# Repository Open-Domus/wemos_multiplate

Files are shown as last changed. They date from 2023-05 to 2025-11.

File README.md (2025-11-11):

# Wemos Multiplate

Wemos Multiplate is a modular, ESPHome-powered front plate for Wemos D1 mini and Wemos S2 mini development boards. It combines presence sensing, environmental telemetry, status lighting, and user inputs into a single wall-friendly enclosure.

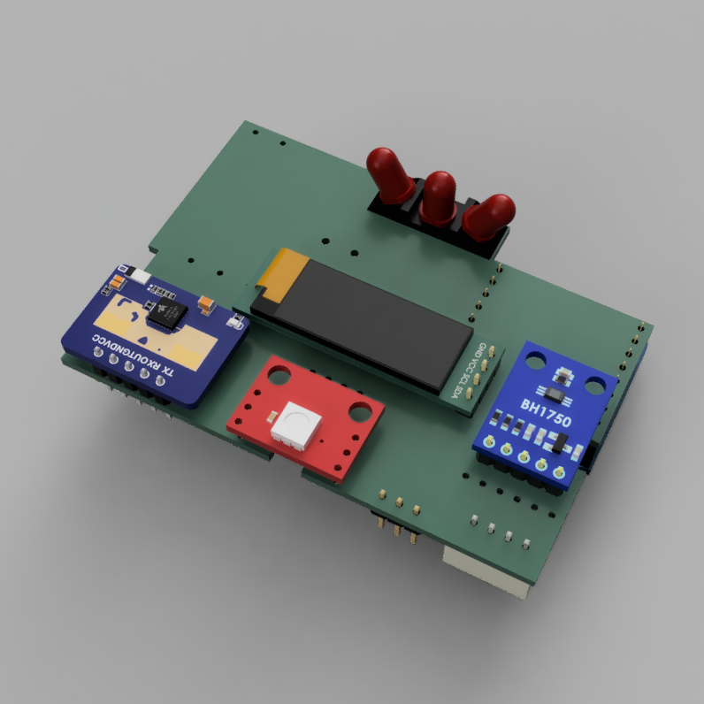
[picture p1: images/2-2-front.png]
front


## Highlights
- Works with Wemos D1 mini (ESP8266) and Wemos S2 mini (ESP32-S2); the S2 mini is strongly recommended if you want every module.
- Integrated 128x64 SSD1306 OLED display with customizable pages.
- Hi-Link LD2410C 24 GHz mmWave presence sensor with optional Bluetooth tuning.
- SHT31-D temperature and humidity probe plus optional BH1750 ambient light and APDS9960 gesture/proximity sensors.
- Two WS2812 addressable LEDs, a piezo buzzer, IR transmitter/receiver, and a header for an external relay module.
- ESPHome package-based configuration lets you enable only the hardware you soldered.

## Repository Layout
- `esphome/` – modular ESPHome configuration split by board (`modules_d1mini/`, `modules_s2mini/`) and shared components (`modules_common/`). Sample automations are under `esphome/automations/`.
- `kicad/wemos-esphome-shield/` – KiCad project, gerbers, STEP models, and release archives for the PCB.

## Hardware Overview
**Base components**
- Wemos D1 mini or Wemos S2 mini dev board (USB-C S2 mini preferred).
- 128x64 I2C OLED display (SSD1306).
- Hi-Link LD2410C mmWave presence sensor.
- Sensirion SHT31-D temperature and humidity sensor.
- Two WS2812 (5 V) addressable LEDs.
- Piezo buzzer with drive transistor.
- TSOP-style IR receiver and 940 nm IR LED pair.

**Optional add-ons**
- BH1750 illuminance sensor.
- APDS9960 gesture/proximity sensor.
- Three front buttons (requires the S2 mini pinout).
- Header for an external 5 V relay module or other accessories.

PCB fabrication files for the latest revision live in `kicad/wemos-esphome-shield/releases/`.

## Getting Started with ESPHome

1. **Install ESPHome**  
   Follow the [ESPHome installation guide](https://esphome.io/guides/installing_esphome.html) (CLI or Home Assistant add-on). CLI examples below assume `pipx install esphome`.

2. **Create secrets**  
   Copy the sample secrets file and edit it with your Wi-Fi and fallback hotspot credentials:
   ```bash
   cp esphome/modules_s2mini/secrets_sample.yaml esphome/secrets.yaml
   ```
   The same `secrets.yaml` is used by both board profiles.

3. **Pick a base profile**  
   - `esphome/multiplate_s2mini.yml` — ESP32-S2 build with every module enabled.  
   - `esphome/multiplate_d1mini.yml` — ESP8266 build with a reduced feature set. Comment out any modules you did not solder to stay within memory limits.

4. **Enable or disable modules**  
   Each module is loaded via the `packages:` section. Comment out a line to disable the corresponding hardware. For example, to skip the gesture sensor:
   ```yaml
   # gesture_sensor: !include modules_common/gesture_sensor.yml
   ```

5. **Build and flash**  
   Connect the board over USB and run:
   ```bash
   esphome run esphome/multiplate_s2mini.yml --device /dev/ttyUSB0
   ```
   After the first successful flash you can go OTA:
   ```bash
   esphome run esphome/your-device-name.yml
   ```

6. **Adopt in Home Assistant**  
   The node exposes all sensors, lights, switches, and buttons via the ESPHome API. Home Assistant will prompt to adopt the new device and automatically create entities.

## Module Reference

| Module | File | Notes |
|---|---|---|
| Core board setup & Wi-Fi | `modules_d1mini/common.yml`, `modules_s2mini/common.yml` | Handles board selection, Wi-Fi credentials, API, OTA. |
| OLED display, pages, and fonts | `modules_common/display.yml`, `font/retrogaming.ttf` | Provides readout and trend pages with a 4 h temperature graph. |
| LD2410C mmWave presence | `modules_d1mini/motion_sensor.yml`, `modules_s2mini/motion_sensor.yml` | Exposes presence, moving/still targets, distance, and Bluetooth control. |
| Temperature & humidity (SHT31-D) | `modules_common/temp_sensor.yml` | Includes a median filter and linear calibration datapoints. |
| Ambient light (BH1750) | `modules_common/light_sensor.yml` | Optional, comment out if the sensor is not populated. |
| Gesture & proximity (APDS9960) | `modules_common/gesture_sensor.yml` | Optional, provides four gesture binary sensors and calibrated proximity. |
| RGB status LEDs | `modules_d1mini/rgb_leds.yml`, `modules_s2mini/rgb_leds.yml` | Two WS2812 LEDs mapped in the sample automations. |
| Buzzer | `modules_d1mini/buzzer.yml`, `modules_s2mini/buzzer.yml` | Template buttons trigger predefined alert patterns. |
| IR transmitter/receiver | `modules_d1mini/ir_remote.yml`, `modules_s2mini/ir_remote.yml` | Exposes `ir_remote` transmitter ID and raw receiver for learning codes. |
| Relay header | `modules_d1mini/relay.yml`, `modules_s2mini/relay.yml` | Optional GPIO-controlled 5 V relay output. |
| Front buttons (S2 mini only) | `modules_s2mini/buttons.yml` | Three debounced GPIO inputs. |
| Automations (display & LEDs) | `automations/display_motion.yml`, `automations/motion_status_leds.yml` | Opt-in template switches to toggle display blanking and LED indicators. |

## Built-in Automations
- `display_motion` keeps the OLED blank until motion is detected, then shows the readout page.
- `motion_status_leds` maps moving and still target detection to the two WS2812 LEDs.

Enable or disable these from the `packages:` block just like the hardware modules.

## Tuning the LD2410C mmWave Sensor
1. Enable the Bluetooth switch entity (`*-ld2410-bluetooth`) exposed by ESPHome.
2. Use the official Android configuration app: <https://play.google.com/store/apps/details?id=com.hlk.hlkradartool>.
3. Connect to the sensor, enter Engineering Mode, and adjust the eight detection gates to match your room layout. Lower values increase sensitivity.
4. Apollo Automation maintains a detailed tuning guide: <https://wiki.apolloautomation.com/books/msr-1/page/how-to-tune-mmwave-using-home-assistant>.

Keeping the heavy tuning UI out of ESPHome reduces load on the D1 mini and shortens boot times.

## Using the IR Remote
Add climate, media, or switch components to your ESPHome profile and reference the shared `ir_remote` transmitter and `ir_rx` receiver IDs. Example:

```yaml
climate:
  - platform: daikin
    name: ${device_name}-climate
    transmitter_id: ir_remote
    receiver_id: ir_rx
```

Use the `remote_receiver` in learning mode (`dump: raw`) to capture codes from your existing remote.

## Manufacturing Files
- Latest gerber sets: `kicad/wemos-esphome-shield/gerber/`
- STEP models for enclosure work: `kicad/wemos-esphome-shield/step/`
- Release bundles (gerbers, BOM, pick-and-place): `kicad/wemos-esphome-shield/releases/`

Send the gerber ZIP to your PCB manufacturer of choice, then populate the board according to the silkscreen and BOM in the release archive.

---

Questions, improvements, or pull requests are welcome!

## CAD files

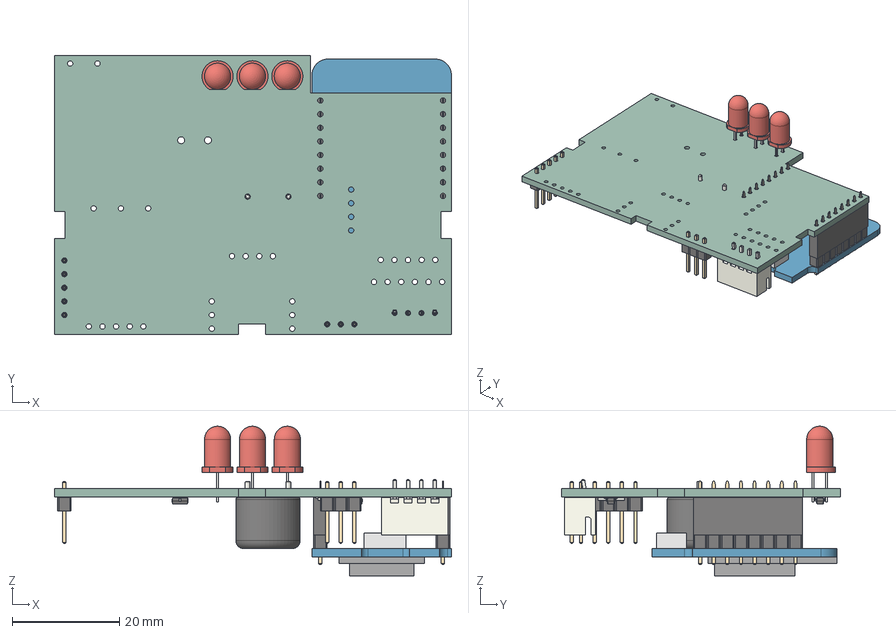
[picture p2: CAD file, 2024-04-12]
kicad/wemos-esphome-shield/step/pcb v2-1.step
74.0 x 52.0 x 27.9 mm
LED_D5.0mm x 3
SOT_23 x 3
R_1206_3216Metric x 8
PinHeader_1x03_P254mm_Vertical
Buzzer_12x95RM76
wemos_d1_mini_light
PinHeader_1x08_P254mm_Vertical x 2
PinSocket_1x08_P254mm_Vertical x 2
JST_B4B_XH_A
PinHeader_1x05_P254mm_Vertical
wemos-esphome-shield PCB

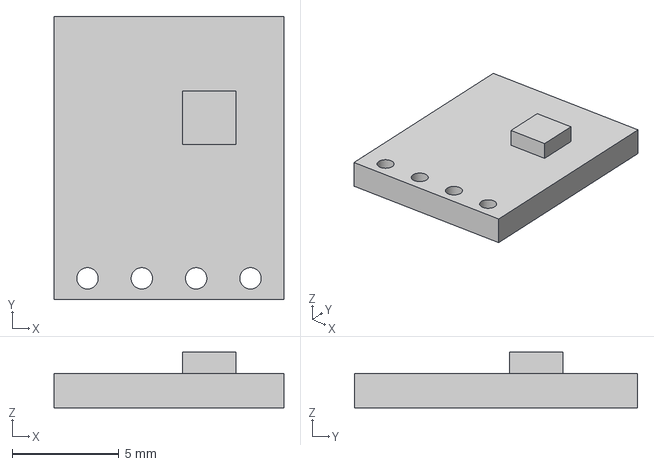
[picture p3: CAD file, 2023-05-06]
kicad/wemos-esphome-shield/step/SHT3X v1.step
10.8 x 13.2 x 2.60 mm

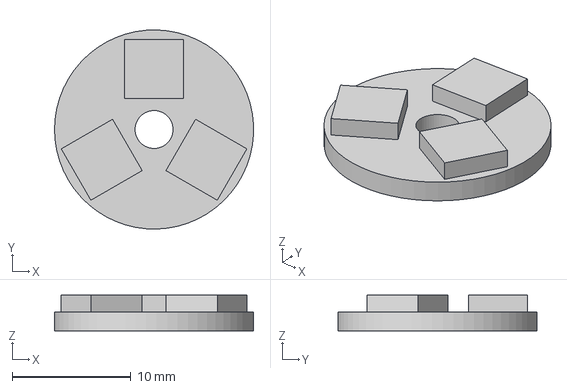
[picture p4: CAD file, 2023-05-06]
kicad/wemos-esphome-shield/step/LED ring v1.step
16.8 x 16.8 x 3.00 mm

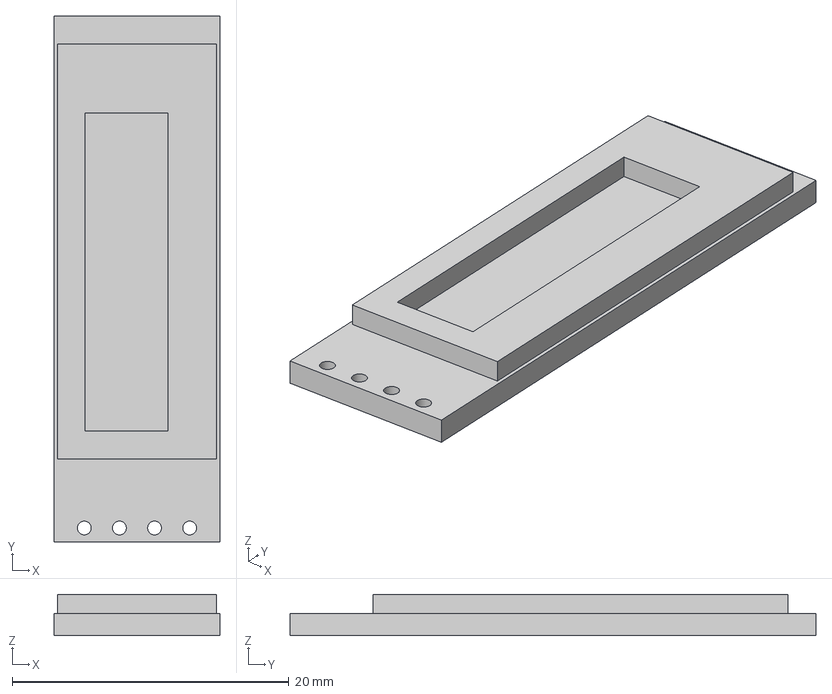
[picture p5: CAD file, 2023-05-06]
kicad/wemos-esphome-shield/step/OLED 0.91 v3.step
12.0 x 38.0 x 3.00 mm

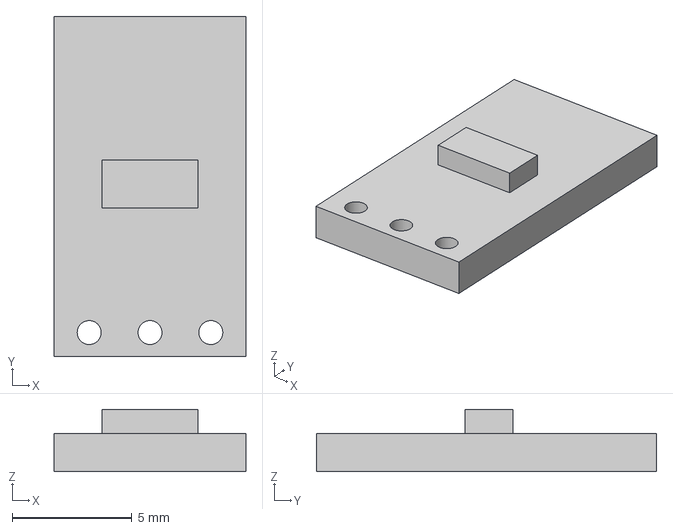
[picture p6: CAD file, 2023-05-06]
kicad/wemos-esphome-shield/step/TEMT6000 v2.step
8.00 x 14.2 x 2.60 mm

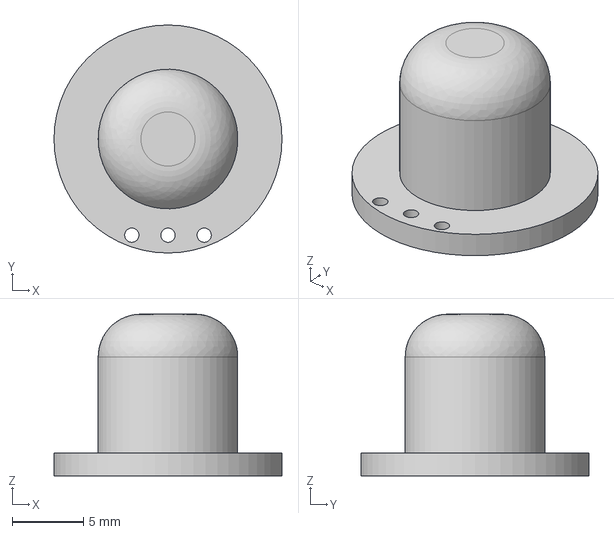
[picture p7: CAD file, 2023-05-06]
kicad/wemos-esphome-shield/step/SR602 v1.step
16.0 x 16.0 x 11.3 mm

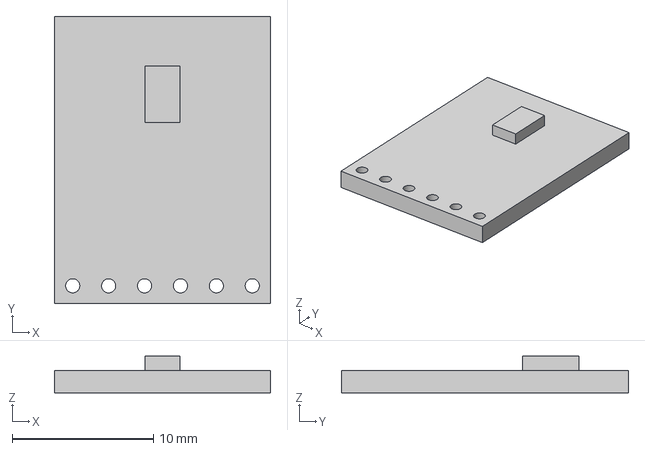
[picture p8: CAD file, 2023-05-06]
kicad/wemos-esphome-shield/step/APDS9960 (new) v3.step
15.3 x 20.3 x 2.60 mm

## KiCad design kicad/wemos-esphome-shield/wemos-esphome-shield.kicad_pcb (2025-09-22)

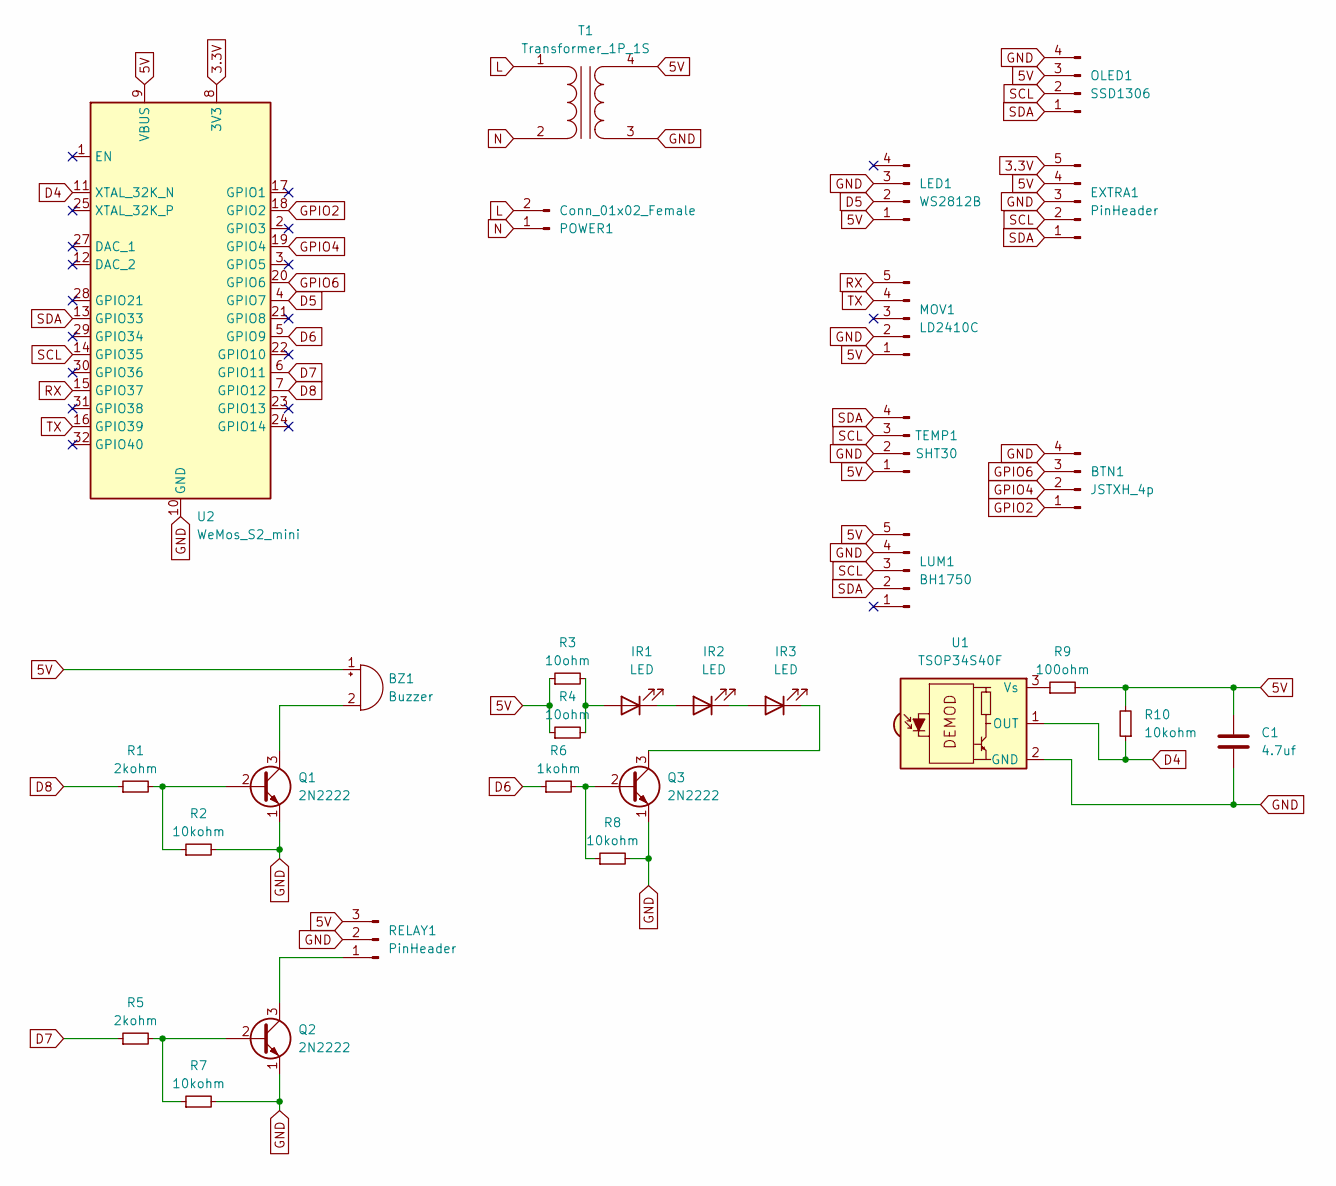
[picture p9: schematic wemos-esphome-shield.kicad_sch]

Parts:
BTN1: JSTXH_4p; JST_XH_B4B-XH-A_1x04_P2.50mm_Vertical
BZ1: Buzzer; Buzzer_12x9.5RM7.6
C1: 4.7uf; C_1206_3216Metric_Pad1.33x1.80mm_HandSolder
EXTRA1: PinHeader; PinHeader_1x05_P2.54mm_Vertical
IR1, IR2, IR3: LED; LED_D5.0mm
LED1: WS2812B; LED breakout
LUM1: BH1750
MOV1: LD2410C
OLED1: SSD1306; SSD1306 OLED 128x64
POWER1: Conn_01x02_Female; TerminalBlock_MetzConnect_Type094_RT03502HBLU_1x02_P5.00mm_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
Q1, Q2, Q3: 2N2222; SOT-23_Handsoldering
R1, R5: 2kohm; R_1206_3216Metric_Pad1.30x1.75mm_HandSolder
R2, R7, R8, R10: 10kohm; R_1206_3216Metric_Pad1.30x1.75mm_HandSolder
R3, R4: 10ohm; R_1206_3216Metric_Pad1.30x1.75mm_HandSolder
R6: 1kohm; R_1206_3216Metric_Pad1.30x1.75mm_HandSolder
R9: 100ohm; R_1206_3216Metric_Pad1.30x1.75mm_HandSolder
RELAY1: PinHeader; PinHeader_1x03_P2.54mm_Vertical
T1: Transformer_1P_1S; 220v AC to 5v DC Transformer
TEMP1: SHT30; JST_XH_B4B-XH-A_1x04_P2.50mm_Vertical
U1: TSOP34S40F; Vishay_MOLD-3Pin
U2: WeMos_S2_mini; WEMOS_S2_mini

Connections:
3.3V: EXTRA1.5, U2.8 (3V3)
5V: BZ1.1 (+), C1.1, EXTRA1.4, LED1.1, LUM1.5, MOV1.1, OLED1.3, R3.1, R4.1, R9.2, R10.2, RELAY1.3, T1.4 (SB), TEMP1.1, U2.9 (VBUS)
D4: R10.1, U1.1 (OUT), U2.11 (XTAL_32K_N)
D5: LED1.2, U2.4 (GPIO7)
D6: R6.1, U2.5 (GPIO9)
D7: R5.1, U2.6 (GPIO11)
D8: R1.1, U2.7 (GPIO12)
GND: BTN1.4, C1.2, EXTRA1.3, LED1.3, LUM1.4, MOV1.2, OLED1.4, Q1.1 (E), Q2.1 (E), Q3.1 (E), R2.2, R7.2, R8.2, RELAY1.2, T1.3 (SA), TEMP1.2, U1.2 (GND), U2.10 (GND), U2.26 (GND)
GPIO2: BTN1.1, U2.18 (GPIO2)
GPIO4: BTN1.2, U2.19 (GPIO4)
GPIO6: BTN1.3, U2.20 (GPIO6)
L: POWER1.2, T1.1 (AA)
N: POWER1.1, T1.2 (AB)
unnamed: BZ1.2 (-), Q1.3 (C)
unnamed: IR1.2 (A), R3.2, R4.2
unnamed: IR1.1 (K), IR2.2 (A)
unnamed: IR2.1 (K), IR3.2 (A)
unnamed: IR3.1 (K), Q3.3 (C)
unnamed: Q1.2 (B), R1.2, R2.1
unnamed: Q2.2 (B), R5.2, R7.1
unnamed: Q2.3 (C), RELAY1.1
unnamed: Q3.2 (B), R6.2, R8.1
unnamed: R9.1, U1.3 (Vs)
RX: MOV1.5, U2.15 (GPIO37)
SCL: EXTRA1.2, LUM1.3, OLED1.2, TEMP1.3, U2.14 (GPIO35)
SDA: EXTRA1.1, LUM1.2, OLED1.1, TEMP1.4, U2.13 (GPIO33)
TX: MOV1.4, U2.16 (GPIO39)

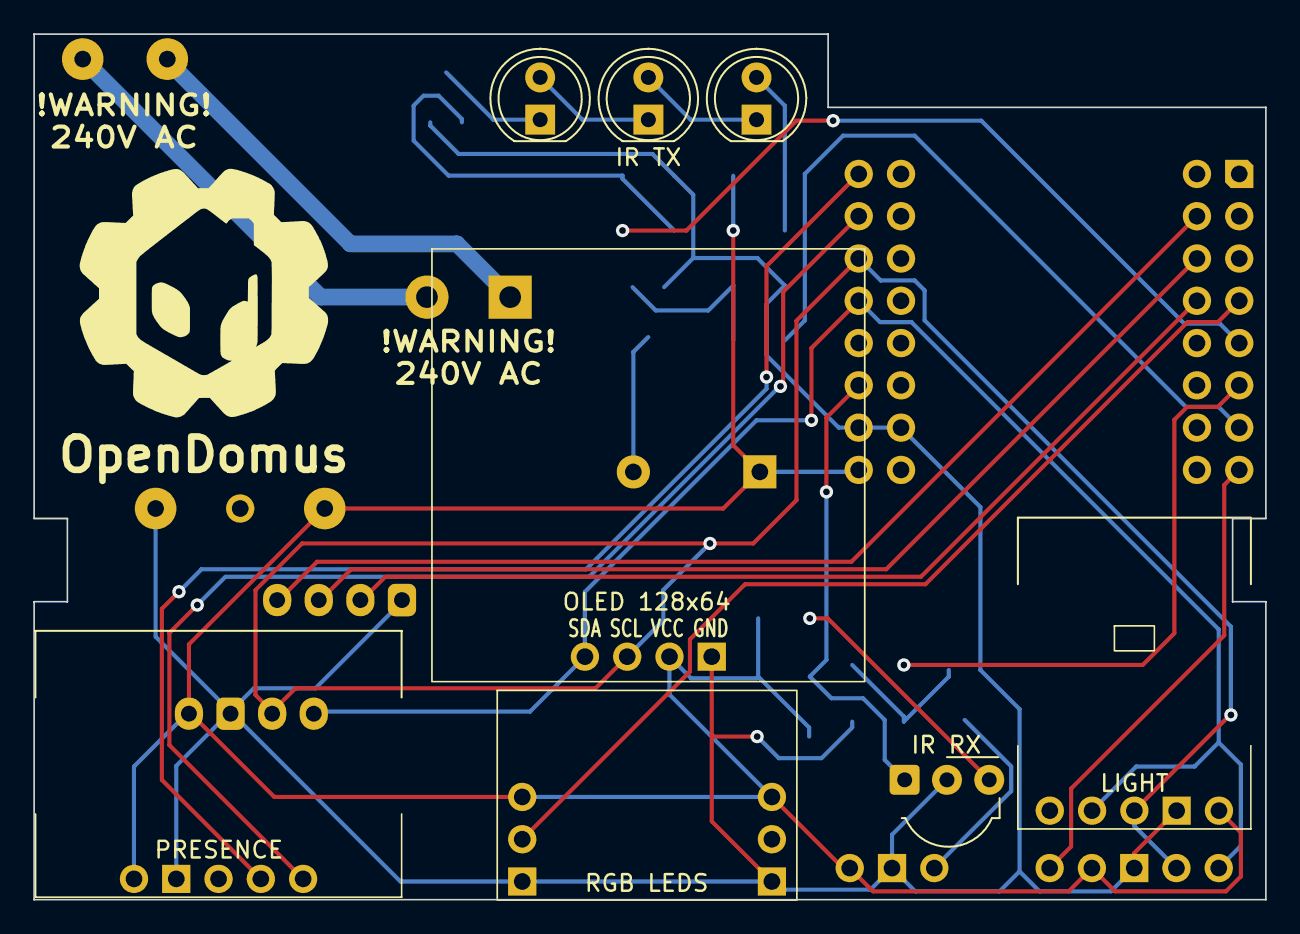
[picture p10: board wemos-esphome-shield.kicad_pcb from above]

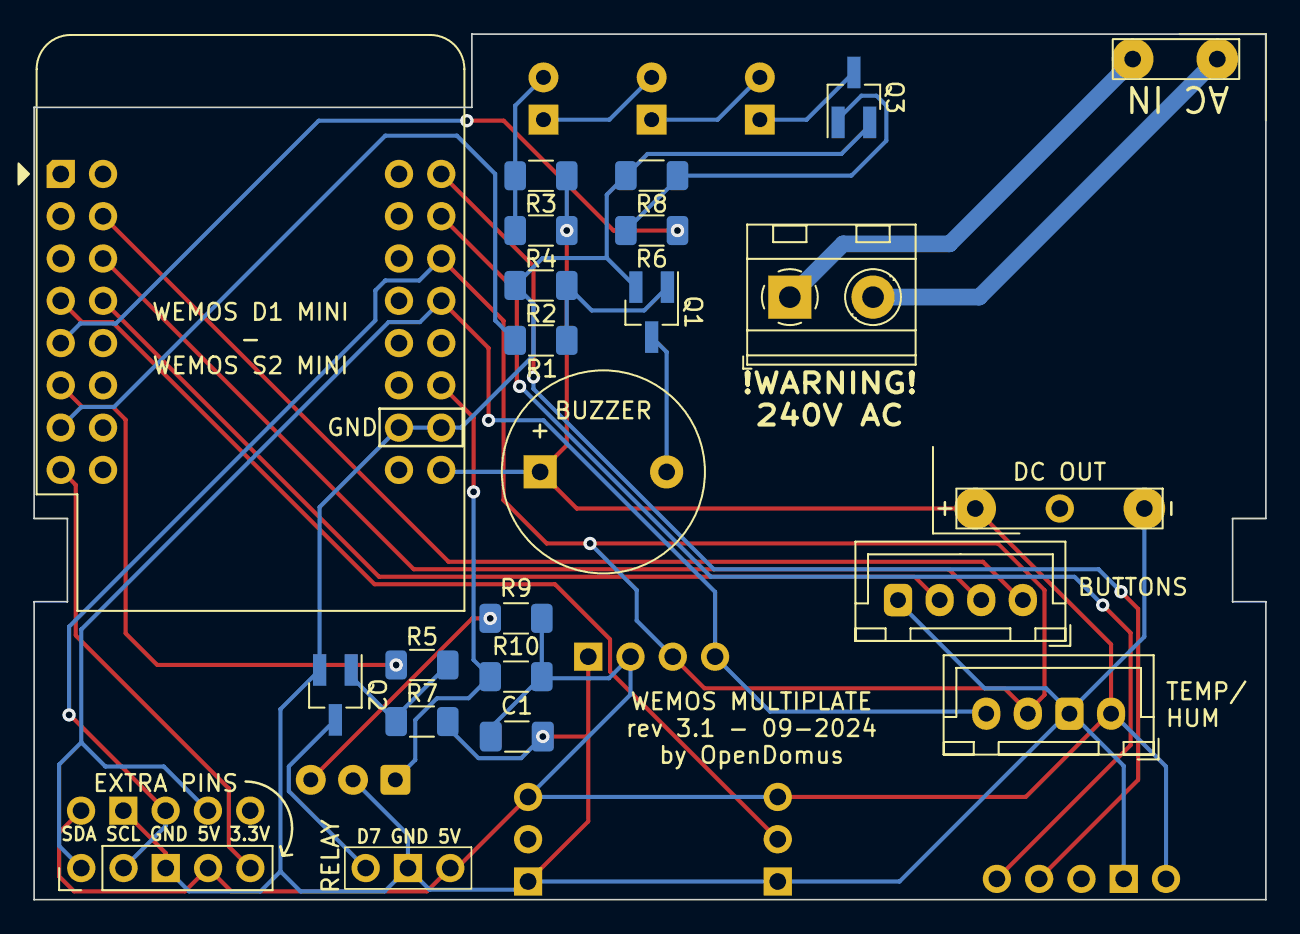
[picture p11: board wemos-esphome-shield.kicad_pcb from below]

Board: 2 copper layers, 74.0 x 52.0 mm, 30 parts (22 on the bottom side), 27 nets.

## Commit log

2023-03-30 move sensors and relay2
    [wemos-esphome-shield.kicad_pcb]
2023-03-30 fix leds footprint
    [wemos-esphome-shield.kicad_pcb]
2023-04-06 Fix some electrical net, new cut edge, new netclasses
    [wemos-esphome-shield.kicad_pcb, wemos-esphome-shield.kicad_sch]
2023-04-06 first routing version
    [wemos-esphome-shield.kicad_pcb]
2023-04-07 update APDS footprint for future compatibility
    [wemos-esphome-shield.kicad_pcb, wemos-esphome-shield.kicad_sch]
2023-04-14 transistor driven relay pin, expose more extra pins, and routing
    [wemos-esphome-shield.kicad_pcb, wemos-esphome-shield.kicad_sch]
2023-04-17 add oled screen pads
    [wemos-esphome-shield.kicad_pcb, wemos-esphome-shield.kicad_sch]
2023-04-18 change temp sensor in yml
2023-04-18 fix logos
    [wemos-esphome-shield.kicad_pcb]
2023-04-19 fix schema and routing for APDS9960
    [wemos-esphome-shield.kicad_pcb, wemos-esphome-shield.kicad_sch]
2023-05-04 updated confs for rgb leds
2023-05-06 added component step files
    [APDS9960 (new) v3.step, LED ring v1.step, OLED 0.91 v3.step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]
2023-05-11 add hyphens to device names, add svg
2024-01-31 footprint fixes
    [wemos-esphome-shield.kicad_pcb, wemos-esphome-shield.kicad_sch]
2024-02-16 new footprints
    [wemos-esphome-shield.kicad_sch]
2024-02-16 fix footprints and schematic
    [wemos-esphome-shield.kicad_sch]
2024-02-16 update schematic
    [wemos-esphome-shield.kicad_sch]
2024-03-12 update schematics
    [wemos-esphome-shield.kicad_sch]
2024-03-13 update footprints
2024-03-13 first positioning of footprints
    [wemos-esphome-shield.kicad_pcb, wemos-esphome-shield.kicad_sch]
2024-03-13 wire tracks
    [wemos-esphome-shield.kicad_pcb, wemos-esphome-shield.kicad_sch]
2024-03-13 rev2 sent to jlcpcb
    [wemos-esphome-shield.kicad_pcb]
2024-03-14 route gesture sensor to 3.3v power
    [wemos-esphome-shield.kicad_pcb, wemos-esphome-shield.kicad_sch]
2024-03-29 custom SOT-23 footprint and other small adjustments
    [wemos-esphome-shield.kicad_pcb, wemos-esphome-shield.kicad_sch]
2024-03-29 center oled display
    [wemos-esphome-shield.kicad_pcb]
2024-04-11 reroute buzzer to D8
    [wemos-esphome-shield.kicad_pcb, wemos-esphome-shield.kicad_sch]
2024-04-12 add step file and update readme
    [pcb v2-1.step]
2024-04-13 move stuff around
    [wemos-esphome-shield.kicad_pcb, wemos-esphome-shield.kicad_sch]
2024-04-13 rev2.2 sent to jlcpcb
    [wemos-esphome-shield.kicad_pcb]
2024-04-18 fix some tracks
    [wemos-esphome-shield.kicad_pcb]
2024-05-03 expose copies of motion sensors to make automations compile
2024-05-08 fix motion automation and proximity sensor calibration
2024-05-21 add median filter to sensors
2024-06-12 reset gesture sensor defaults
2024-06-30 move pcb references
    [wemos-esphome-shield.kicad_pcb]
2024-07-15 fix s2 mini buzzer pin
2024-07-21 fix relay pin on wemos s2 mini
2024-08-13 add buttons module
2024-08-18 Fix PCB to use Wemos S2 mini (#2)
    * cleanup libraries
    * added buttons and ir receiver. rerouted everything
    [wemos-esphome-shield.kicad_pcb, wemos-esphome-shield.kicad_sch]
2024-08-19 rev3 sent to jlcpcb
    [wemos-esphome-shield.kicad_pcb]
2025-09-22 cleanup kicad
    [wemos-esphome-shield.kicad_pcb, wemos-esphome-shield.kicad_sch]
2025-09-22 add switches to toggle automations
2025-09-23 fix bug in buttons.yml
2025-09-23 motion activated relay plugin
2025-11-11 board specific improvements and updates for esphome 2025.10.4
2025-11-29 add raw temp sensor and calibration
